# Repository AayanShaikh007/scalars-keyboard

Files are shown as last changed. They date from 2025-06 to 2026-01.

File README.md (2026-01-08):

# KB-01 - Custom Keyboard Fully Engineered from scratch
**Scroll down to see the finished product + YT demo!**

A custom made keyboard, built + designed completely in house!   

## Description
I've always wanted to make a mechanical keyboard, and after owning two proprietary keyboards, I had an idea of what features I wanted to incorporate in my final design. To begin, I love the OLED display in the high end steelseries keyboards, so that was a must-add. One of my keyboards, a Corsair K65, broke after I tried to fix a malfunctioning switch and damaged the board, shorting the traces for a few surrounding keys. It is due to this that I decided to make this keyboard hot-swappable, so that you can easily swap switches (mx and kalih). 

Assembled Board (Switches here are red, but should actually be brown):





PCB (3d and editor) (Note: 3d rendering of PCB does not show silkscreen- see pcb editor screenshot for updated view of pcb)







## BOM:

| Item | Amount | Bought? | Cost | Notes | Link |
|---|---|---|---|---|---|
| ----ALL PRICES IN CAD---- | null | null | null | null | ----ALL PRICES IN CAD---- |
| Switches (need 89) | 1 set of 90 + 1 set of 20 (backups) | null | 50.33+16.99| strongly think that backups will be needed due to faulty switches | https://www.amazon.ca/dp/B07X3WKM54?th=1 |
| Kalih hotswap (89) | 1 set of 110 | null | 21.90+7.59 | fast delivery | https://www.amazon.ca/dp/B0BVH3SVHW |
| Diodes (91) | 1 set of 500 | null | 12.34 | cheaper than the sets of 100 | https://www.amazon.ca/dp/B0CP9LXW6J |
| Rotary encoder ec11 | 1 set of 4 | null | 14.89 | somehow one of the cheap yet good quality ones | https://www.amazon.ca/dp/B07GFF3F36 |
| sk6812-mini-E (89) | 1 set of 200 | null | 9.85+5.54  | null | https://www.amazon.ca/dp/B0CYBP7RBR |
| Oled ssd1306 | set of 2 | null | 14.48 | this should NOT cost 15 dollars. I will try to get one shipped with my hackpad, or use that one. | https://www.amazon.ca/dp/B0C7L289Y2 |
| Pico (og) | null | null | 16.87 | cheapest + usbc | https://www.amazon.ca/dp/B0CDLDTV19 |
| Stabilizers (10) --> 3d printable| null | null | 22.04+5.09 | null | https://www.amazon.ca/dp/B0CTHP7F8M |
| Keycaps | 1 set | null | 18.97 | Cheap and look good | https://www.amazon.ca/dp/B0CNXLW2MP |
| Rubber anti-slip pads | 1 set | null | 4.00 | null | local dollarama |
| Long USB Cable (data) | 1 set | null | 8.54 | cheapest one i could find in pack of 2 - might try Dollarama if it supports data | https://www.amazon.ca/dp/B089DM4KDW |
| PCB Manufacturing cost | 1 | null | 49.80 | yikes | null |
| TOTAL PRICE | null | null | 254.56 CAD ~ 186 USD | This can be lowered if I get some parts (ec11, diodes, oled) from hack club HQ | null |

Amazon parts cost comes out to 168.87 CAD, leaving 36 dollars for pcb

# Finished Product



# Youtube Demo

https://youtu.be/qIi-tUGdEp4

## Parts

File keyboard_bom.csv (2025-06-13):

Item | Amount | Bought? | Cost | Notes | Link
----ALL PRICES IN CAD---- |  |  |  |  | ----ALL PRICES IN CAD----
---components---
Switches (need 89) | 1 set of 90 + 1 set of 20 (backups) |  | 50.33+16.99 | strongly think that backups will be needed due to faulty switches | https://www.amazon.ca/dp/B07X3WKM54?th=1
Kalih hotswap (89) | 1 set of 110 |  | 21.90+7.59 | fast delivery | https://www.amazon.ca/Hot-swap-CPG151101S11-Mechanical-Keyboard-Accessories/dp/B0BVH3SVHW?s=electronics
Diodes (91) | 1 set of 500 |  | 12.34 | cheaper than the sets of 100 | https://www.amazon.ca/Electronic-Conponents-Switching-Rectifier-Isolation/dp/B0CP9LXW6J
Rotary encoder ec11 | 1 set of 4 |  | 14.89 | somehow one of the cheap yet good quality ones | https://www.amazon.ca/Gikfun-Encoder-Digital-Potentiometer-EK2045x4C/dp/B07GFF3F36
sk6812-mini-E (89) | 1 set of 200 |  | 9.85+5.54 |  | https://www.amazon.ca/cogae-Similar-WS2812B-Individually-Addressable/dp/B0CYBP7RBR
Oled ssd1306 | set of 2 |  | 14.48 | this should NOT cost 15 dollars. I will try to get one shipped with my hackpad, or use the one on my hackpad. | https://www.amazon.ca/LFRANK-Pieces-Display-Module-SSD1306/dp/B0C7L289Y2?rnid=3276483011&rps=1
Pico (og) |  |  | 16.87 | cheapest + usbc | https://www.amazon.ca/DIGISHUO-Raspberry-Pi-Pico-Pink/dp/B0CDLDTV19
---cosmetic parts---
Stabilizers (10) --> 3d printable |  |  | 22.04+5.09 |  | https://www.amazon.ca/DUROCK-Stabilizer-Innovative-Pre-Clipped-Stabilizers/dp/B0CTHP7F8M
Keycaps | 1 set |  | 18.97 | Cheap and look good | https://www.amazon.ca/Mintcaps-Painting-Sublimation-Switches-Mechanical/dp/B0CNXLW2MP?rnid=12035759011
Rubber anti-slip pads | 1 set |  | 4.00 |  | local dollarama
Long USB Cable (data) | 1 set |  | 8.54 | cheapest one i could find was in a pack of 2 - might get this from the dollar store if it has data transfer | https://www.amazon.ca/Charging-etguuds-Charger-Compatible-Samsung/dp/B089DM4KDW
---manufacturing---
PCB Manufacturing cost | 1 |  | 49.80 | yikes
Library 3d printing cost | - |  | ~20 | ill pay for this
TOTAL PRICE |  |  | 222.56 | This can be lowered significantly if i get some parts (ec11, diodes, oled) from hack club hq

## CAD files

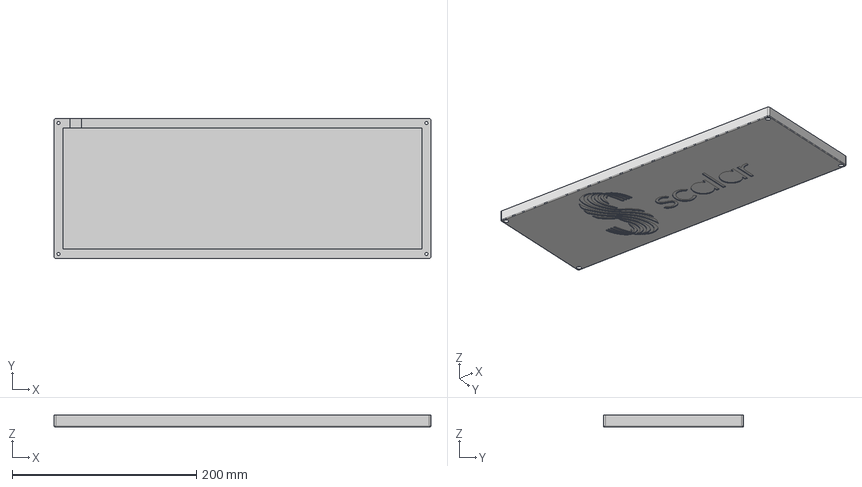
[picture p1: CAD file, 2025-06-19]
CAD/individual_parts/base v4.step
409.3 x 152.1 x 13.0 mm

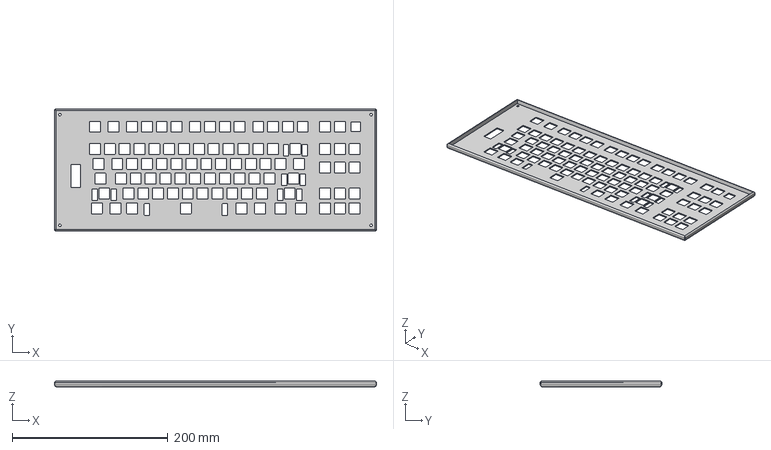
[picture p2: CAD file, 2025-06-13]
CAD/individual_parts/top v4.step
413.3 x 156.1 x 7.50 mm

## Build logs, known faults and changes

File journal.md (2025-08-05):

---
title: "Scalar's Keyboard"
author: "@Scalar on slack"
description: "A TKL Keyboard made fully in house"
created_at: "2025-06-09"
---
Estimated Total Time: 27 hours

✅ : implemented already

# June 9th, 12:06 PM - First Update Since Project Start - 3h
I have been thinking of this project for a while but was delayed due to some setbacks with my hackpad, which means I will need to accelerate work on this project. I began by doing some research of various aspects/qualities of keyboards, and decided which ones I wanted to implement in my final design. 

In my final design, I really want ...
- Hotswappable keys. This will be achieved by using Kalih Hot-swappable sockets, which are fortunately compatible with all MX style switches.
- ✅ OLED Display for mode display (probably SSD1306)
- ❎ ~~Customizable RGB screen/display, for showing custom animations (SSD1331 perhaps).~~ After further research, this has proven too difficult to implement in in a keyboard, and I will implement this in my other custom project. 

Some more standard features ...
- ✅ Mode setting keys.
- ✅ Macros powered by a custom software where display settings, etc can be controlled.
- ✅ Either a built in kickstand or some attachment/feature to increase the angle of the keyboard (3d printable after assembly).
- ✅ A foam/soft touch wristpad. (will order from amazon after project completion)

# June 9th, 11:59 AM - Finalizing Project Goals - 1h

Before starting work on the schematic, I performed further research on some other aspects of the keyboard I wanted in my final design. I was thinking of using the Sparkfun Pro Micro rp2040 chip as my microcontroller, but I decided against it and will be using a Pico (v1) instead. The only con i can think of with regards to this is that I wont have USB-C connectivity, but that can be fixed by replacing the microcontroller with a clone from alibaba after highway is complete (I only want parts that can be shipped + recieved within 7 days). 
- ✅ The microcontroller will be a Raspberry Pi Pico
- ✅ I will be using MX Brown switches (ideally)

# June 10th ~1:00 AM - 3h
- Continued working on the schematic. ~~I have finished the key matrix and will be using the Adafruit MCP23017 to increase pinouts.~~ Decided to remove this
- https://www.digikey.ca/en/products/detail/adafruit-industries-llc/5346/15913270
- ✅ I will also be adding a EC11 rotary encoder, it should be helpful for volume/mode settings.

# June 10th 5:33 AM - 4h
- Completed Schematic. It was somewhat tedious and took longer than expected but everything looks good at the end at least. Will begin work on PCB now.

Low Res Preview of Schematic: 



# June 10th ~5:30 PM, ~6h
- Completed PCB. My experience with hackpad helped in this quite a bit. For some reason the keys didnt line up properly but I think I got everything in the right place (measured to confirm).

Preview of PCB:



# June 11th
Instead of wiring the PCB, once I had arranged the switches/parts and was satisfied with they position, I worked on the 3D files of the keyboard so I could make changes to the structure while I still had the chance. I used the hackpad guide for this and it helped me greatly. Once this was finished I began wiring the PCB.

# June 12th 10:49 PM, ~10h
- Finally, after probably 10 hours of work, I have finished wiring the PCB. This was so unbelievably complicated and strenuous- this project may even be the most challenging thing I have done.



This should conclude the project! I will add updates as I assemble the actual parts. 

# July 3rd 
Now that all parts have arrived, i began soldering the board. i started small by just soldering a couple of diodes for today.



# July 4th
I wanted to test some components before soldering them onto the PCB. I tested the pico, and once that was secured to the PCB, I worked on getting some of the firmware to work. All components work as intended thus far. It took me quite some time to get the hang of uploading firmware to the pico by way of adding the files to the circuitpy drive. etc. 

# July 5th and 6th 
I spent the last two days just soldering all of the remaining kalih hotswap sockets and diodes. Other than that, I soldered some small components such as the rotary encoder and the OLED panel. Now with the PCB finished, I got ready to test the firmware and the pcb by putting in all the keyswitches. 



# July 7th and 8th. 
I worked on the firmware of the keyboard for these two days. I quickly realized that my original code was completely broken because it was untested and would not work. Due to this, I needed to completely make my code from scratch (fortunately it wasnt many lines). I discovered something odd with either my keyboard or KMK- for some reason the code wouldnt work when I added any keys to the next row but if I just kept adding keys to the first line they would register. At least the code works, although it might be pretty unsightly (check screenshot). I also started printing the case.



# July 17th
After undercity, I got back to work on the case of the keyboard. After printing a number of failed top plate designs, I realized that I could print one that fits inside the case, flush with the top of the case. After spending around 1-2 hours modelling the top plate, I printed a plate that actually fit properly. I then spent a few hours removing all of the keycaps and keyswitches, inserting them into the top plate, and securing them to the pcb again. This essentially concludes the build process.



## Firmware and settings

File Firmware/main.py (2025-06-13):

import board
import busio

from kmk.kmk_keyboard import KMKKeyboard
from kmk.keys import KC
from kmk.scanners import DiodeOrientation
from kmk.modules.macros import Macros

from kmk.extensions.display import Display, TextEntry
from kmk.extensions.LED import LED, AnimationModes
from kmk.extensions.display.ssd1306 import SSD1306


col_0 = board.GP00
col_1 = board.GP01
col_2 = board.GP08
col_3 = board.GP09
col_4 = board.GP012
col_5 = board.GP013
col_6 = board.GP016
col_7 = board.GP017
col_8 = board.GP026


row_0 = board.GP02
row_1 = board.GP03
row_2 = board.GP06
row_3 = board.GP07
row_4 = board.GP010
row_5 = board.GP011
row_6 = board.GP014
row_7 = board.GP015
row_8 = board.GP018
row_9 = board.GP019

d_pin = board.GP8

oled_bus = busio.I2C(board.GP_SCL, board.GP_SDA)

oled_driver = SSD1306(i2c=oled_bus, device_address=0x3C);

display = Display(
    display=oled_driver,
    width=128,
    height=32, 
    dim_time=10,
    dim_target=0.2,
    off_time=1200,
    brightness=0.8
);

keyboard = KMKKeyboard()
keyboard.diode_orientation = DiodeOrientation.COL2ROW # the stripe (+) points towards the row 

keyboard.col_pins = (col_0, col_1, col_2, col_3);
keyboard.row_pins = (row_0, row_1, row_2, row_3);

keyboard.keymap = [
    [KC.ESC, KC.F1, KC.F2, KC.F3, KC.F4, KC.F5, KC.F6, KC.F7, KC.F8, KC.F9, KC.F10, KC.F11, KC.F12],
    
    [KC.GRAVE, KC.N1, KC.N2, KC.N3, KC.N4, KC.N5, KC.N6, KC.N7, KC.N8, KC.N9, KC.N0, KC.MINUS, KC.EQUAL, KC.BSPC],
    
    [KC.TAB, KC.Q, KC.W, KC.E, KC.R, KC.T, KC.Y, KC.U, KC.I, KC.O, KC.P, KC.LBRACKET, KC.RBRACKET, KC.BSLASH],
    
    [KC.CAPSLOCK, KC.A, KC.S, KC.D, KC.F, KC.G, KC.H, KC.J, KC.K, KC.L, KC.SCOLON, KC.QUOTE, KC.ENTER],
    
    [KC.LSHIFT, KC.Z, KC.X, KC.C, KC.V, KC.B, KC.N, KC.M, KC.COMMA, KC.DOT, KC.SLASH, KC.RSHIFT],
    
    [KC.LCTRL, KC.LGUI, KC.LALT, KC.SPACE, KC.RALT, KC.RGUI, KC.APP, KC.RCTRL],
    #Home/arrow keys/macros ???

]


if __name__ == '__main__':
    keyboard.go()

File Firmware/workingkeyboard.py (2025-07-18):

import board
import busio

from kmk.kmk_keyboard import KMKKeyboard
from kmk.keys import KC
from kmk.scanners import DiodeOrientation
from kmk.modules.macros import Macros

# from kmk.extensions.display import Display, TextEntry
# from kmk.extensions.LED import LED, AnimationModes
# from kmk.extensions.display.ssd1306 import SSD1306


col_0 = board.GP0  # Column0
col_1 = board.GP1  # Column1
col_2 = board.GP8  # Column2
col_3 = board.GP9  # Column3
col_4 = board.GP12 # Column4
col_5 = board.GP13 # Column5
col_6 = board.GP16 # Column6
col_7 = board.GP17 # Column7
col_8 = board.GP26


row_0 = board.GP2
row_1 = board.GP3
row_2 = board.GP6
row_3 = board.GP7
row_4 = board.GP10
row_5 = board.GP11
row_6 = board.GP14
row_7 = board.GP15
row_8 = board.GP18
row_9 = board.GP19

keyboard = KMKKeyboard()
keyboard.diode_orientation = DiodeOrientation.COL2ROW # the stripe (+) points towards the row 

keyboard.col_pins = (col_0, col_1, col_2, col_3, col_4, col_5, col_6, col_7, col_8);
keyboard.row_pins = (row_0, row_1, row_2, row_3, row_4, row_5, row_6, row_7, row_8, row_9);


keyboard.keymap = [
    [KC.ESC, KC.KP_ASTERISK, KC.F1, KC.F2, KC.F3, KC.F4, KC.F5, KC.F6, KC.F7, KC.F8, KC.F9, KC.F10, KC.F11, KC.F12, KC.PSCREEN, KC.DELETE, KC.KP_4, KC.KP_5, KC.KP_6, KC.KP_3, KC.KP_2, KC.KP_1, KC.N8, KC.N9, KC.N0, KC.MINUS, KC.EQUAL, KC.RBRACKET, KC.GRAVE, KC.N1, KC.N2, KC.N3, KC.N4, KC.N5, KC.N6, KC.N7, KC.Q, KC.W, KC.E, KC.R, KC.T, KC.Y, KC.U, KC.I, KC.O, KC.A, KC.S, KC.D, KC.F, KC.G, KC.H, KC.J, KC.K, KC.L, KC.Z, KC.X, KC.C, KC.V, KC.B, KC.N, KC.M, KC.COMMA, KC.DOT, KC.P, KC.LBRACKET, KC.SCOLON, KC.QUOTE, KC.SLASH, KC.LALT, KC.LEFT, KC.DOWN, KC.RIGHT, KC.KP_7, KC.UP, KC.KP_9, KC.LCTRL, KC.LGUI, KC.RALT, KC.RGUI, KC.RCTRL, KC.TAB, KC.BSLASH, KC.MENU, KC.CAPSLOCK, KC.BSPC, KC.ENTER, KC.LSHIFT, KC.RSHIFT, KC.SPACE, KC.KP_MINUS],  # Row 0
    [KC.F9, KC.F10, KC.F11, KC.F12, KC.PSCREEN, KC.GRAVE, KC.N1, KC.N2, KC.N3],  # row 1 test
    [KC.F1]*9,
    [KC.NO, KC.N1, KC.N2, KC.N3, KC.N4, KC.N5, KC.NO, KC.NO, KC.NO],
    [KC.F2]*9,
    [KC.F3]*9,
    [KC.F4]*9,
    [KC.F5]*9,
    [KC.F6]*9,
    [KC.F7]*9,
]


if __name__ == '__main__':
    keyboard.go()





# d_pin = board.GP8

# oled_bus = busio.I2C(board.GP_SCL, board.GP_SDA)

# oled_driver = SSD1306(i2c=oled_bus, device_address=0x3C);

# display = Display(
#     display=oled_driver,
#     width=128,
#     height=32, 
#     dim_time=10,
#     dim_target=0.2,
#     off_time=1200,
#     brightness=0.8
# );

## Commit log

2025-06-13 all files
    [base v4.step, keyboard.kicad_sch, keyboard_bom.csv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]
2025-06-13 brown switches
2025-06-19 ar ar ar ar
    [base v4.step]
